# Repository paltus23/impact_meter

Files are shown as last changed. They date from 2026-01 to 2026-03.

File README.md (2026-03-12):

## Device Description

* The accelerometer board is based on the ESP32-C3FH4 microcontroller and the ADXL375 accelerometer.
* The device can be powered either from a battery or via USB. When USB is connected, the battery is automaticly disconnected over MOSFET.
* The USB port is connected using wires. It is used to power the device, flash firmware, and perform debugging.
* A spare UART port is available for firmware flashing and debugging.
* Several additional GPIOs are brought out to test points for possible future use.
* Communication is performed via Wi-Fi.
* Recording and transmission of data are intended to be carried out at different times (not simultaneously).

## Impact meter v1
There is few photos of ready device
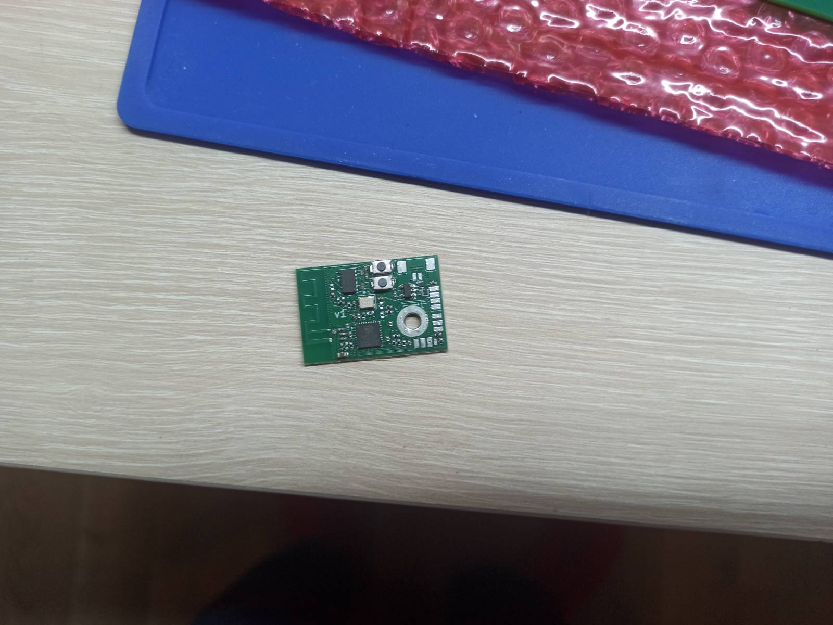
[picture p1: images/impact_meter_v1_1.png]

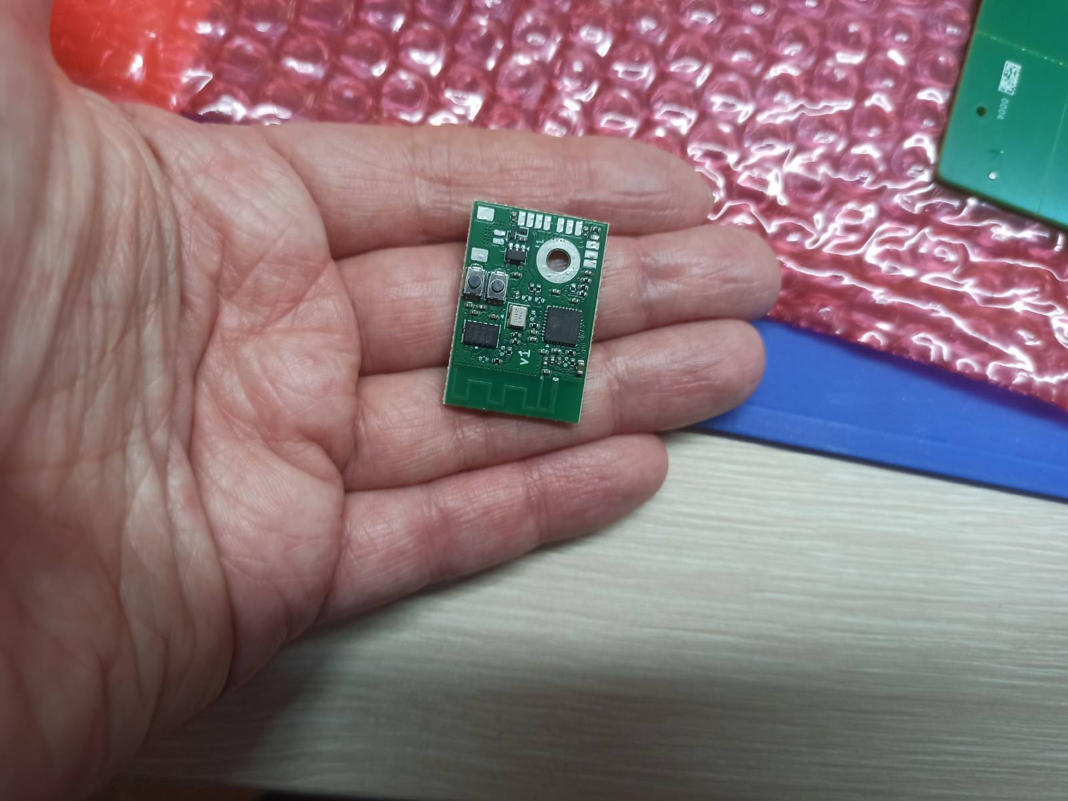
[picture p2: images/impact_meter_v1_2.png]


## v1 known issues
3.3 V power supply do not connected to ESP32

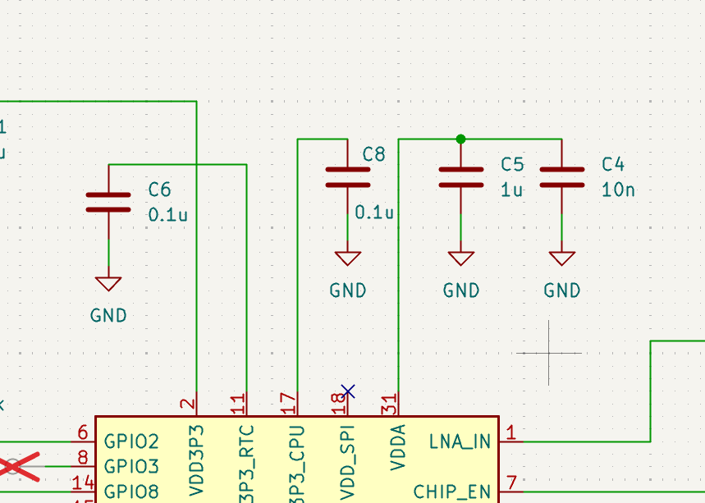
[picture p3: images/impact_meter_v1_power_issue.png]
power issue


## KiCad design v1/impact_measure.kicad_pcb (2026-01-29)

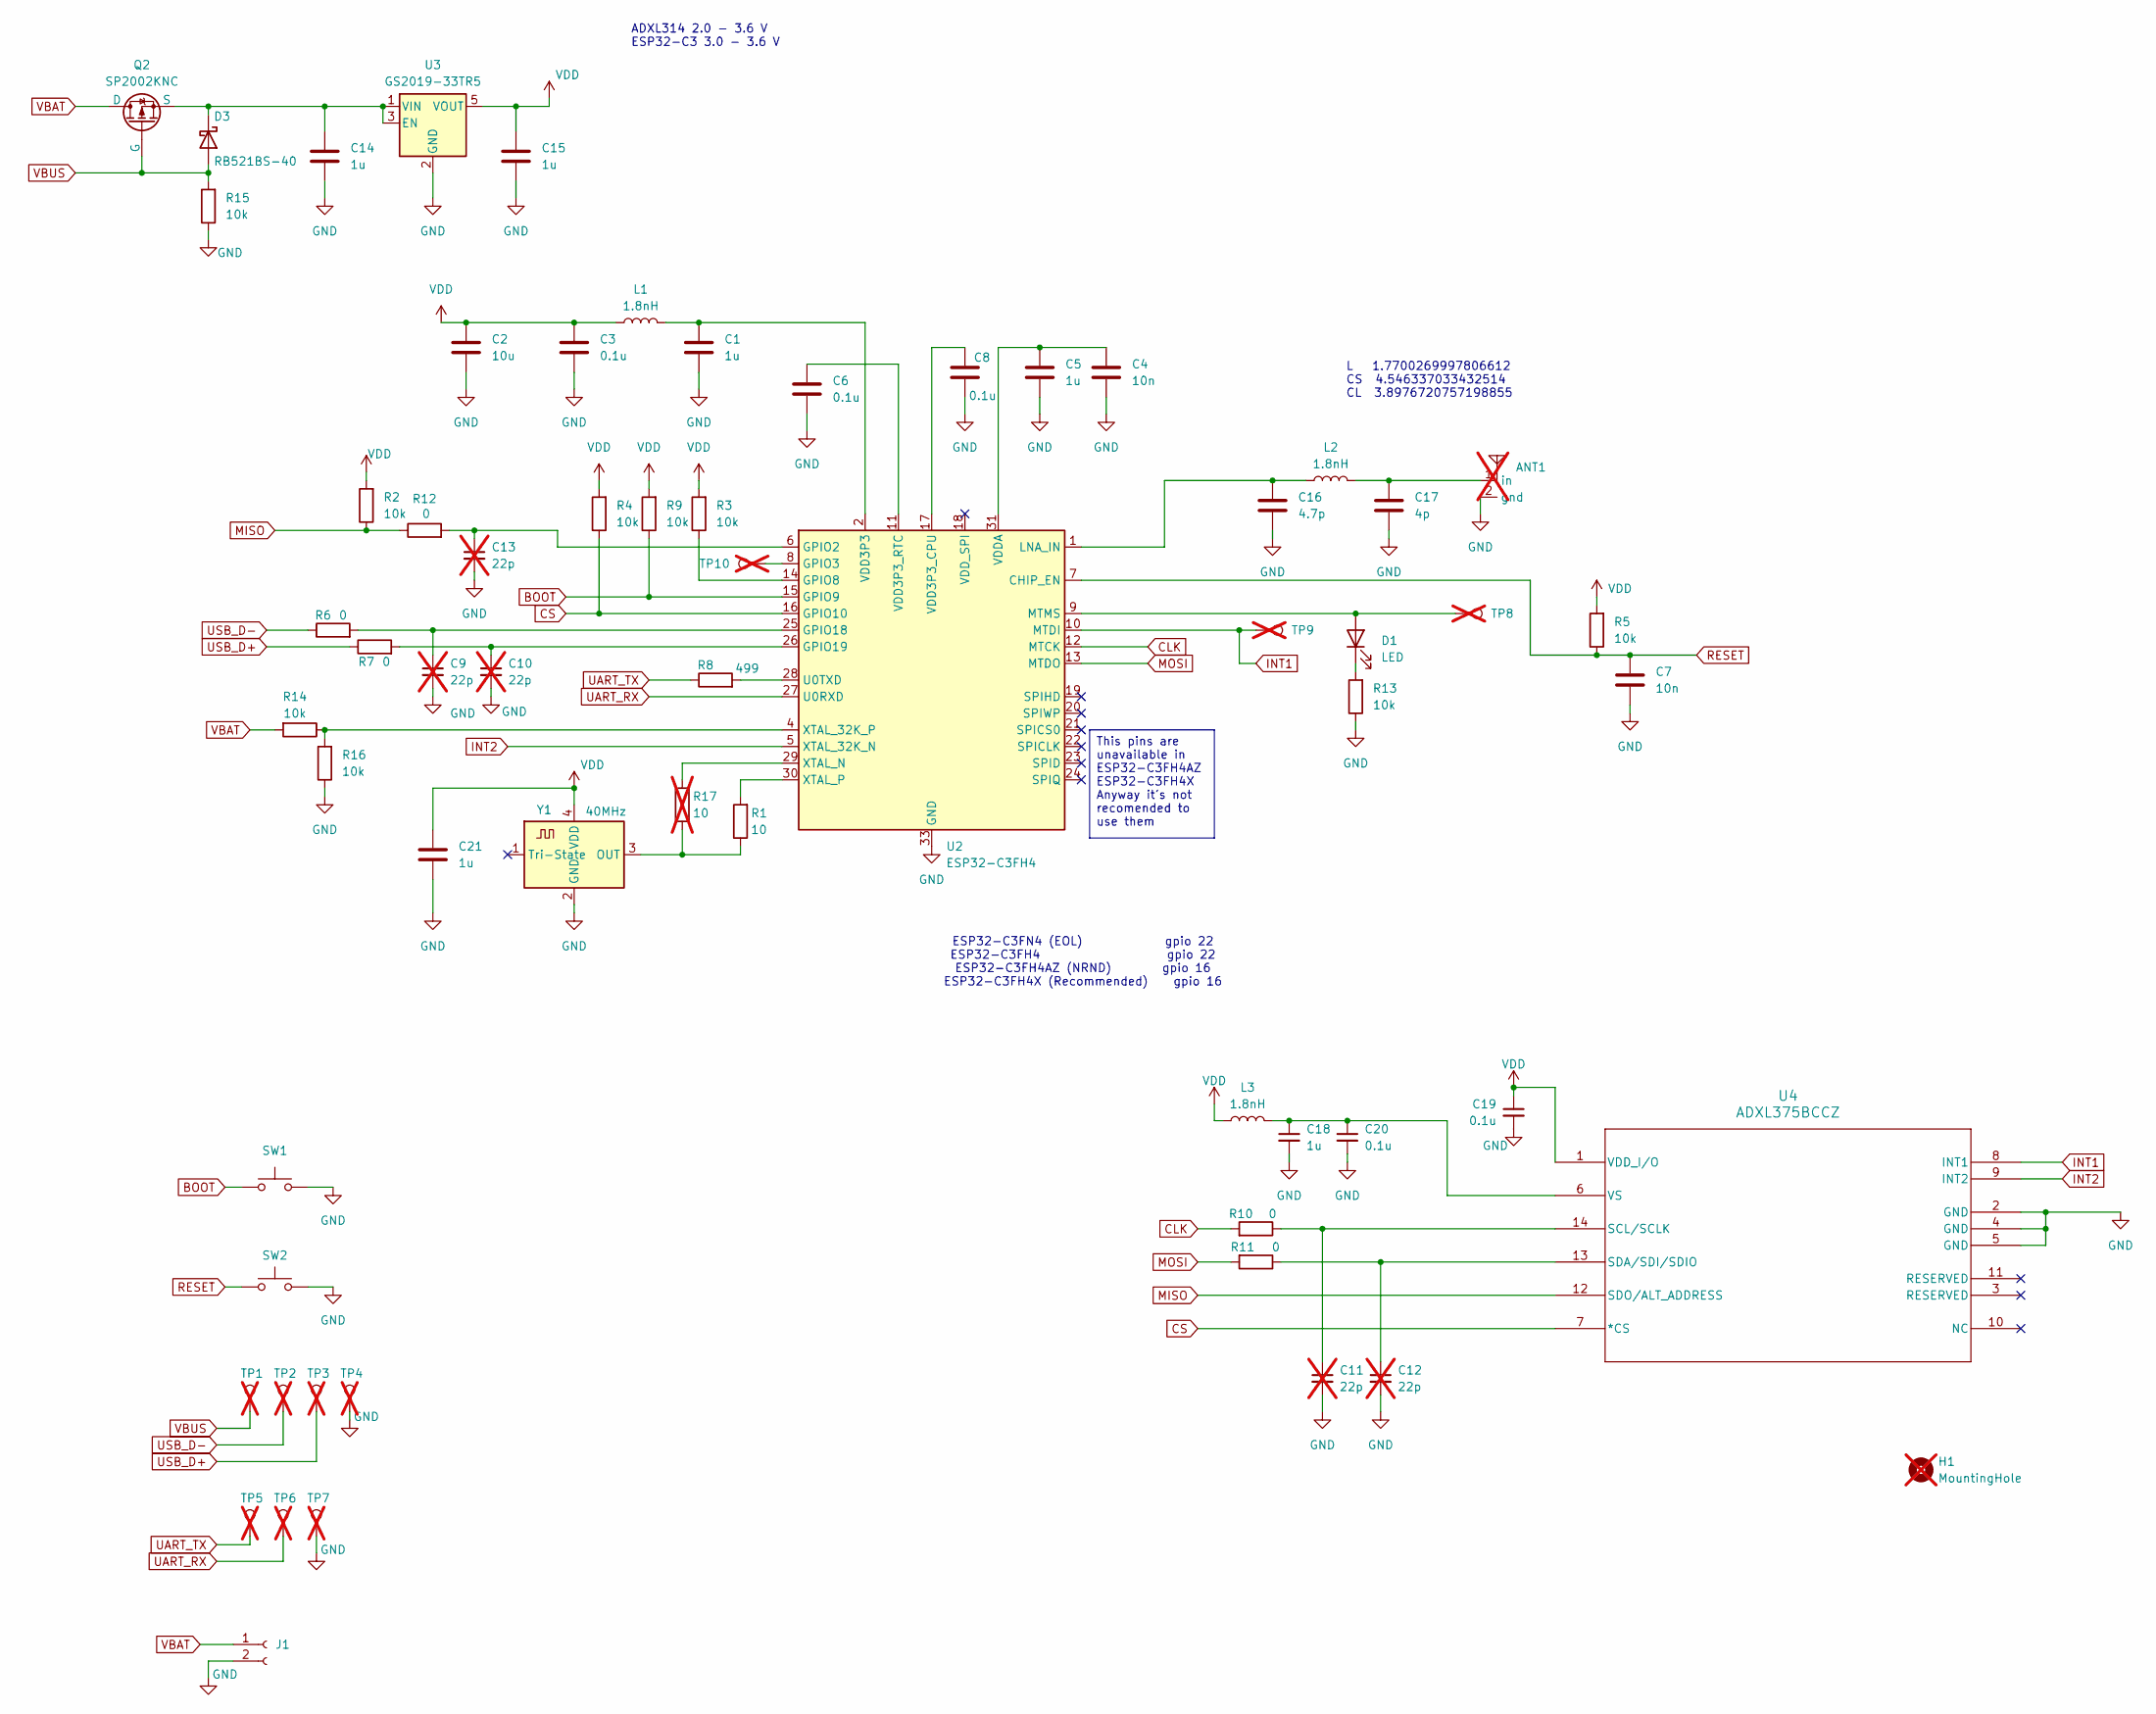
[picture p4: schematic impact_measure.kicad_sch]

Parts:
ANT1: 2_4GHz_AN043; not fitted
C1, C5, C14, C15, C18, C21: 1u; C_0402_1005Metric; PartNumber CC0402KRX5R6BB105; LCSC C106254
C2: 10u; C_0603_1608Metric; PartNumber CC0402KRX5R6BB105; LCSC C109453
C3, C6, C8, C19, C20: 0.1u; C_0402_1005Metric; PartNumber CC0402KRX7R7BB104; LCSC C60474
C4, C7: 10n; C_0402_1005Metric; PartNumber CC0402MRX7R6BB103; LCSC C527020
C9, C10, C11, C12, C13: 22p; C_0402_1005Metric; PartNumber CC0402JRNPO8BN220; LCSC C541361; not fitted
C16: 4.7p; C_0402_1005Metric; PartNumber CGA0402C0G4R7C500GT; LCSC C20069279
C17: 4p; C_0402_1005Metric; PartNumber CSA0402C0G4R0C500GT; LCSC C48642896
D1: LED; LED_0402_1005Metric; PartNumber GL0402YG01; LCSC C51933305
D3: RB521BS-40; D_SOD-882; PartNumber RB521BS-40; LCSC C53207092
H1: MountingHole; MountingHole_3.2mm_M3; not fitted
J1: Bossie BX-MX1.25-2PWT; mx1.25; LCSC C18077932
L1, L2, L3: 1.8nH; L_0402_1005Metric; PartNumber VHF100505HQ1N8ST; LCSC C395057
Q2: SP2002KNC; Diodes_DFN1006-3; PartNumber SP2002KNC; LCSC C41354895
R1: 10; R_0402_1005Metric; PartNumber RC0402FR-0710RL; LCSC C138066
R2, R3, R4, R5, R9, R13, R14, R15, R16: 10k; R_0402_1005Metric; PartNumber RC0402FR-0710KL; LCSC C60490
R6, R7, R10, R11, R12: 0; R_0402_1005Metric; PartNumber RC0402FR-070RL; LCSC C106231
R8: 499; R_0402_1005Metric; PartNumber RC0402FR-07499RL; LCSC C137970
R17: 10; R_0402_1005Metric; not fitted
SW1, SW2: SW_Push; SW_Push_SPST_NO_Alps_SKRK; PartNumber TS-1088-AR02016; LCSC C720477
TP1, TP2, TP3, TP4, TP5, TP6, TP7, TP8, TP9, TP10: TestPoint; TP_1x2mm; not fitted
U2: ESP32-C3FH4; QFN-32-1EP_5x5mm_P0.5mm_EP3.7x3.7mm; PartNumber ESP32-C3FH4; LCSC C2858491
U3: GS2019-33TR5; SOT-23-5; PartNumber GS2019-33TR5; LCSC C41419378
U4: ADXL375BCCZ; LGA_CC-14-1_ADXL375; PartNumber ADXL375BCCZ; LCSC C579466
Y1: 40MHz; Oscillator_SMD_Abracon_ASE-4Pin_3.2x2.5mm; PartNumber OW2EL89CENUXK7YLC-40M; LCSC C48888233

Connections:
BOOT: R9.1, SW1.1, U2.15 (GPIO9)
CLK: R10.2, U2.12 (MTCK)
CS: R4.1, U2.16 (GPIO10), U4.7 (*CS)
GND: ANT1.2 (gnd), C1.2, C2.2, C3.2, C4.2, C5.2, C6.2, C7.2, C8.2, C9.2, C10.2, C11.2, C12.2, C13.2, C14.2, C15.2, C16.2, C17.2, C18.2, C19.2, C20.2, C21.2, J1.2, R13.1, R15.1, R16.1, SW1.2, SW2.2, TP4.1, TP7.1, U2.33 (GND), U3.2 (GND), U4.2 (GND), U4.4 (GND), U4.5 (GND), Y1.2 (GND)
INT1: TP9.1, U2.10 (MTDI), U4.8 (INT1)
INT2: U2.5 (XTAL_32K_N), U4.9 (INT2)
MISO: R2.1, R12.1, U4.12 (SDO/ALT_ADDRESS)
MOSI: R11.2, U2.13 (MTDO)
unnamed: ANT1.1 (in), C17.1, L2.2
unnamed: C1.1, L1.2, U2.2 (VDD3P3), U2.3 (VDD3P3)
unnamed: C4.1, C5.1, U2.31 (VDDA), U2.32 (VDDA)
unnamed: D1.2 (A), TP8.1, U2.9 (MTMS)
unnamed: D1.1 (K), R13.2
unnamed: C14.1, D3.1 (K), Q2.2 (S), U3.1 (VIN), U3.3 (EN)
unnamed: C13.1, R12.2, U2.6 (GPIO2)
unnamed: TP10.1, U2.8 (GPIO3)
unnamed: R3.1, U2.14 (GPIO8)
unnamed: C9.1, R6.2, U2.25 (GPIO18)
unnamed: C10.1, R7.2, U2.26 (GPIO19)
unnamed: C16.1, L2.1, U2.1 (LNA_IN)
unnamed: R8.2, U2.28 (U0TXD)
unnamed: C8.1, U2.17 (VDD3P3_CPU)
unnamed: C6.1, U2.11 (VDD3P3_RTC)
unnamed: R14.1, R16.2, U2.4 (XTAL_32K_P)
unnamed: R17.2, U2.29 (XTAL_N)
unnamed: R1.2, U2.30 (XTAL_P)
unnamed: C11.1, R10.1, U4.14 (SCL/SCLK)
unnamed: C12.1, R11.1, U4.13 (SDA/SDI/SDIO)
unnamed: C18.1, C20.1, L3.2, U4.6 (VS)
unnamed: R1.1, R17.1, Y1.3 (OUT)
RESET: C7.1, R5.1, SW2.1, U2.7 (CHIP_EN)
UART_RX: TP6.1, U2.27 (U0RXD)
UART_TX: R8.1, TP5.1
USB_D+: R7.1, TP3.1
USB_D-: R6.1, TP2.1
VBAT: J1.1, Q2.3 (D), R14.2
VBUS: D3.2 (A), Q2.1 (G), R15.2, TP1.1
VDD: C2.1, C3.1, C15.1, C19.1, C21.1, L1.1, L3.1, R2.2, R3.2, R4.2, R5.2, R9.2, U3.5 (VOUT), U4.1 (VDD_I/O), Y1.4 (VDD)

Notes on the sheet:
ESP32-C3FN4 (EOL) gpio 22 ESP32-C3FH4 gpio 22 ESP32-C3FH4AZ (NRND) gpio 16 ESP32-C3FH4X (Recommended) gpio 16
L 1.7700269997806612 CS 4.546337033432514 CL 3.8976720757198855
ADXL314 2.0 - 3.6 V ESP32-C3 3.0 - 3.6 V
This pins are unavailable in ESP32-C3FH4AZ ESP32-C3FH4X Anyway it's not recomended to use them

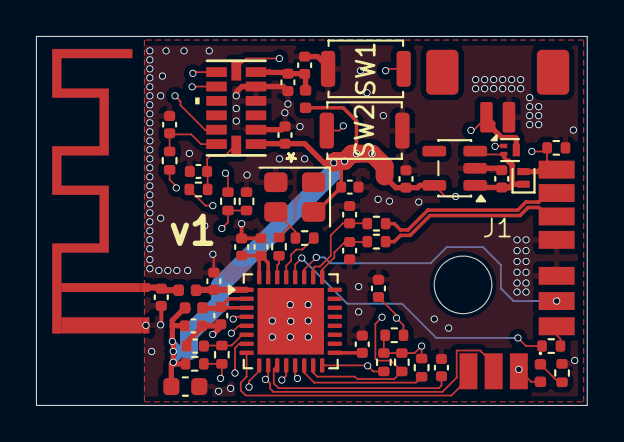
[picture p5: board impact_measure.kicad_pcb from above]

Board: 4 copper layers, 30.6 x 20.5 mm, 63 parts (0 on the bottom side), 38 nets.

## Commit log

2026-01-24 init commit
    [impact_measure.kicad_pcb, impact_measure.kicad_sch]
2026-01-24 move project to v1 directory
    [impact_measure.kicad_pcb, impact_measure.kicad_sch]
2026-01-28 add decap to Y1 quarz change C2 electrolyte to ceramic add signals int1 and int2
    [impact_measure.kicad_sch]
2026-01-29 fixed accel land pattern add via fetching increased m3 keepout diameter add int1 and int2 routes fixed wifi track width to 0,35mm moved 10u decap next to ESP32
    [impact_measure.kicad_pcb, impact_measure.kicad_sch]
2026-01-29 opened mask under screw
    [impact_measure.kicad_pcb]
2026-01-29 fixed LCSC partnumbers fixed after DRC
    [impact_measure.kicad_pcb, impact_measure.kicad_sch]
2026-01-29 added connector for battery
    [impact_measure.kicad_pcb, impact_measure.kicad_sch]
2026-01-29 added vias for gnd fixed after drc
    [impact_measure.kicad_pcb]
2026-03-12 add images of ready device of v1
